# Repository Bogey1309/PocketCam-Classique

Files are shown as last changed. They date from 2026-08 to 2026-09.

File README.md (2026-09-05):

# PocketCam Classique

A tiny retro inspired digital camera built around an ESP32-CAM and OV5640 camera sensor.

## What is PocketCam Classique?

PocketCam Classique is a small digital camera designed and built from scratch as a Hack Club project. (Bonus if I make it keychain sized)
The goal is to make a compact, simple camera inspired by older digital cameras, using cheap electronics and a 3D printed enclosure.

The current design is approximately 55 × 30 × 23 mm.

## Hardware

- ESP32-CAM + OV5640 camera
- 1.54" TFT display
- 3.7V 500mAh LiPo battery
- IP5310 boost converter
- microSD 
- Tactile switches
- 3D printed enclosure

## Current Progress

- [x] Selected electronic components
- [x] Measured components
- [x] Designed internal component layout
- [x] Designed enclosure in Onshape
- [x] Created assembly with internal components
- [x] Designed camera lens opening
- [x] Designed TFT opening
- [x] Refined enclosure design
- [ ] Purchase components
- [ ] 3D print enclosure
- [ ] Assemble electronics
- [ ] Program ESP32
- [ ] Implement image capture
- [ ] Test camera
- [ ] Complete prototype

## CAD

Designed in Onshape around the actual dimensions and placement of the  components.
The visuals look very sharp and boxy.

## Build Plan

1. Purchase the electronics.
2. Assemble and test the electronics.
3. Program the ESP32-CAM.
4. 3d print the enclosure
5. Integrate the electronics into the enclosure.
6. Test the completed camera.

## Funding

Roughly $45 of grants will be needed for the complete build.

## Project Status

**CAD complete. Hardware prototype not yet assembled.**

Images:







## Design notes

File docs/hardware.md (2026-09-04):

**Hardware Architecture**

PocketCam Classique V1 is built from an ESP32CAM with an OV5640 camera module.

Contents:
- ESP32-CAM (AI Thinker)
- OV5640 5MP camera (attached to the ESP32-CAM)
- 1.3" 240x240 ST7789 SPI TFT display, (doesn't have a CS pin)
- microsd card, used in SD_MMC 1-bit mode to save GPIO pins
- 3.7V 500mAh LiPo battery
- IP5310 boost converter (also charging module)
- master power switch (SPST toggle, sits between the IP5310 output and the ESP32-CAM's 5V input)
- shutter button (tactile switch)
- CH340G USB to TTL

The ESP32-CAM only exposes only a few GPIO pins once the camera and onboard PSRAM are accounted for, so component choice and wiring were planned around that  rather than picked first and fitted in later.

Development:
breadboard and jumper cables will be used for the prototype before soldering anything into the final enclosure.

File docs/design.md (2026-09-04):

**Design Notes**

The enclosure is CAD'ed in Onshape around the size of each component.

Current external dimensions are approximately 55 x 30 x 23mm.

Onshape Document Link:
https://cad.onshape.com/documents/e219cd74eb6f8bbdfaefde86/w/89c30a95217f8900fc007d07/e/92d33215c84a0608a1414959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

Design process:
- Measured every component (ESP32-CAM, display, battery, IP5310, switch, button) online
- Built the internal layout first, around where each part physically needs to sit (maximizing space efficiency since i want this to be a keychain cam)
- Designed the enclosure shell around that internal layout
- Polished the enclosure, chamfered it, cut holes for buttons. 

**Design Progression:**
I first measured out the dimensions of the components, then sketched them out on paper. I opened my big box of legos and matched lego pieces to the sketches. Hence I had a good idea of the component sizes. I spent some time trying to arrange the legos in the most space efficient manner.

I then made a rough wiring diagram in draw.io

After that, I opened up onshape and made rough blocks for the components and an enclosure and checked if it all fit. 
I had to make 2 iterations of the enclosure since the first one was not very ergonomic.

I will be using a CH340G to program the ESP32CAM since it does not have a usb port as well.

Attached images:

 _Lego Design_

_Rough draw.io Wiring Diagram_


 _Enclosure V1_





_Enclosure V2_

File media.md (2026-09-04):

Photos and renders:

LEGO build

Enclosure V1 

Enclosure V2 






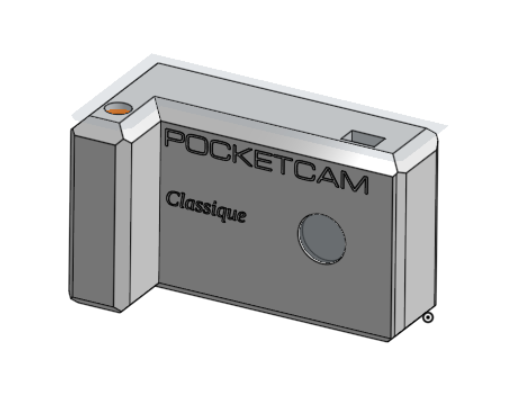
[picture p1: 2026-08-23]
enclosure-v2.png

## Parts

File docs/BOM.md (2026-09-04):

Components, Price, Link

1) ESP32CAM + OV5640 =  **₹1,199**                  
(https://probots.co.in/esp32-cam-development-board-wifi-bluetooth-ov5640-camera.html)

2) 3.7V 500mAh LiPo Battery (502248) - 1.85Wh Lithium Polymer Cell with Protection PCB =  **₹299**
https://probots.co.in/search/3.7v%20500mah

3) 1.3" 240x240 IPS TFT LCD Display Module - Full RGB, ST7789, 7-Pin SPI  =  **₹599**
   https://probots.co.in/1-3-inch-240x240-ips-tft-lcd-module-st7789-spi.html

4) IP5310 5V 3A to 2.4V Lithium Battery Charging Boost Module Type C =  **₹145**
   https://anilestore.com/product/ip5310-5v-3a-to-24v-lithium-battery-charging-boost-module-type-c

5) CH340G USB to TTL Serial Converter Module - 3.3V/5V Logic Programmer  = **₹99**
   https://probots.co.in/ch340g-usb-to-rs232-ttl-auto-converter-adapter-module-for-arduino.html

6) TS3625A-HT 50mA Brick nogging SPST 250gf@±30gf 36V SMD,3.7x6.1mm Tactile Switches  =  **₹7**
   https://probots.co.in/ts3625a-ht-50ma-brick-nogging-spst-250gfat-30gf-36v-smd-3-7x6-1mm-tactile-switches.html

7) DPDT Slide Switch 6 Pin  =  **₹15**
   https://probots.co.in/dpdt-slide-switch.html

8) Mini Push Tactile Switch =  **₹7**
   https://probots.co.in/mini-push-switch.html

9) GL-12 840 Points Solderless Breadboard for Electronics Prototyping & DIY Projects  =  **₹86**
   https://probots.co.in/gl-12-840-points-solderless-breadboard-prototyping.html

10) Male To Female Jumper Wires 40 Pcs 20cm  =  **₹69**
   https://probots.co.in/male-to-female-jumper-wires-40-pcs-20cm.html

11) Male to Male Jumper wires 40 Pcs 20 CM  =  **₹69**
   https://probots.co.in/male-to-male-jumper-wires-40-pcs-20-cm.html

12) HIKVISION Extreme 16GB microSDXC Memory Card Class 10, V30  =  **₹667.09**
   https://www.amazon.in/gp/product/B0GVJZ56K5/ref=ewc_pr_img_1?smid=AJ6SIZC8YQDZX&th=1

13) Digital Multimeter DT830D Low Cost  =  **₹235**
   https://probots.co.in/digital-multimeter-dt830d-low-cost.html

14) 3D Printed PETG Enclosure ≈ **₹200**

15) Multi-stranded Hookup Wire  =  **₹70**
   https://probots.co.in/multi-stranded-hookup-wire.html

 = ₹3,766 + SHIPPING + TAXES

**TOTAL = INR 4350**

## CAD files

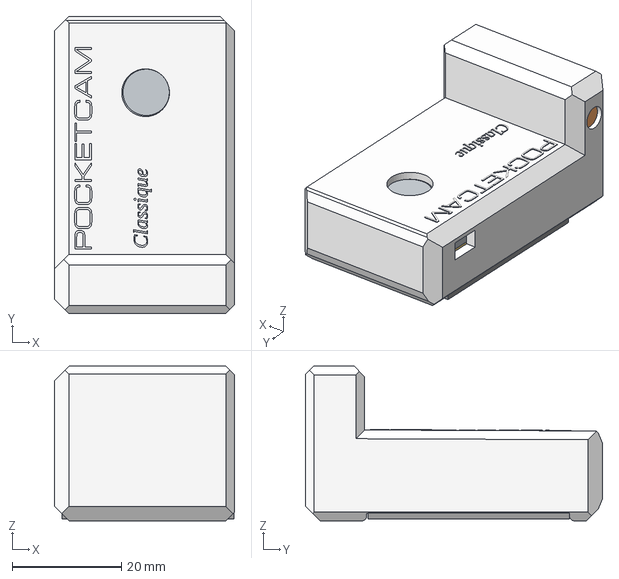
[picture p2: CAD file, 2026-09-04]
Assembly 1 (1).step
33.0 x 54.5 x 28.4 mm

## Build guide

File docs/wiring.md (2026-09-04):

TFT          ESP32-CAM
GND     -    GND
VCC     -    3.3V
SCL     -    GPIO3
SDA     -    GPIO33
RES     -    3.3V
DC      -    GPIO12
BLK     -    3.3V

Shutter
GPIO13 -- [Tactile Button] -- GND

Power
3.7V LiPo --> IP5310 --> [Toggle Switch] --> ESP32-CAM 5V

SD card
Uses the onboard microSD slot, wired internally to GPIO2/14/15 (SD_MMC 1-bit mode). Therefore no external wiring needed for it.

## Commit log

2026-09-04 Add CAD file with Onshape link
2026-09-04 Add media section with images and descriptions
    Added images and descriptions for LEGO builds and enclosures.
2026-09-04 Create BOM.csv with component details and pricing
    Added a Bill of Materials (BOM) with components, prices, and links for reference.
    [BOM.csv]
2026-10-18 Add firmware for PocketCam Classique V1
    Implemented firmware for PocketCam Classique V1 with camera initialization, live preview, and photo capture functionality.
2026-10-18 Update Onshape link in CAD file
2026-10-18 Add Onshape link to CAD file
2026-10-18 Add camera images to README
    Added additional images taken by the camera to the README.
2026-10-18 Create cad files
